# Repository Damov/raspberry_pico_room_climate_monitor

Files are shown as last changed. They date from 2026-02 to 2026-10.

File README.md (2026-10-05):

# Raspberry Pi Pico room climate monitor

A compact system based on the Raspberry Pi Pico designed for monitoring indoor climate conditions. The project integrates a <b>Raspberry Pi Pico 2 (RP2350)</b> microcontroller, a <b>Waveshare 2.7-inch E-Paper display module</b> (264 × 176 pixels), a <b>Waveshare BME280 environmental sensor</b>, and a <b>Hailege SCD41 CO₂ gas sensor</b>. Its purpose is to measure and display room temperature, humidity, atmospheric pressure, and CO₂ concentration. The software architecture is structured to support multiple screen layouts, which can be defined and switched via user input buttons.

# Screenshots

The following images illustrate the assembly of the system on a breadboard using jumper wires for all signal and power connections. The display is configured with a standard layout, presenting 15 minutes of historical data on the left side and three primary metrics on the right side: temperature, humidity, and CO₂ concentration. The four buttons select the home screen, previous layout, next layout, or a full refresh of the current view.

<p align="center">
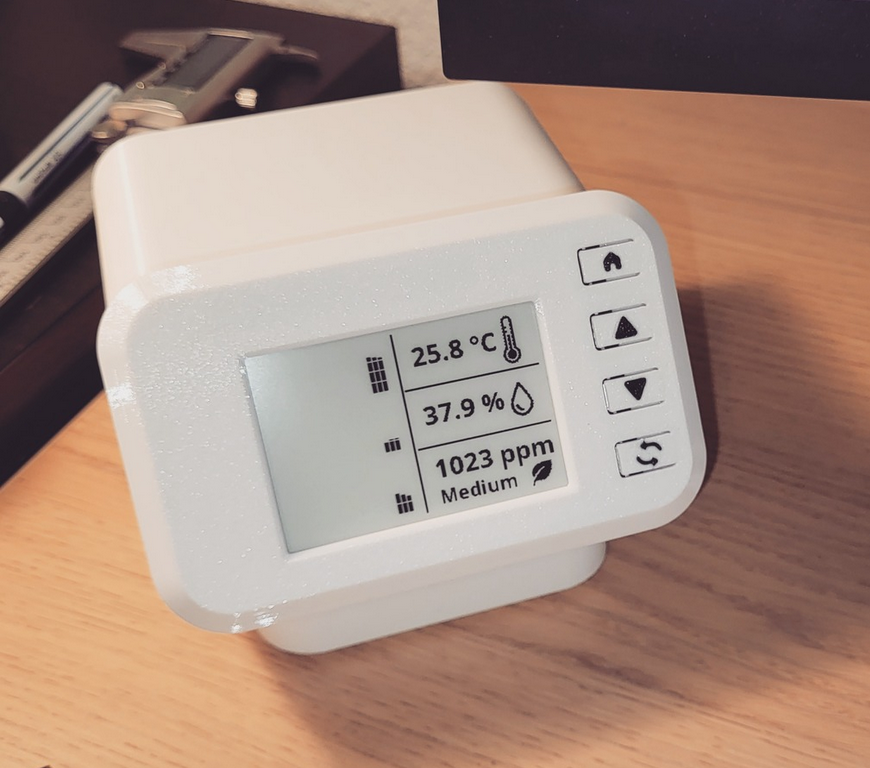
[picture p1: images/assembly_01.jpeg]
Assembly of the system, picture 1
  
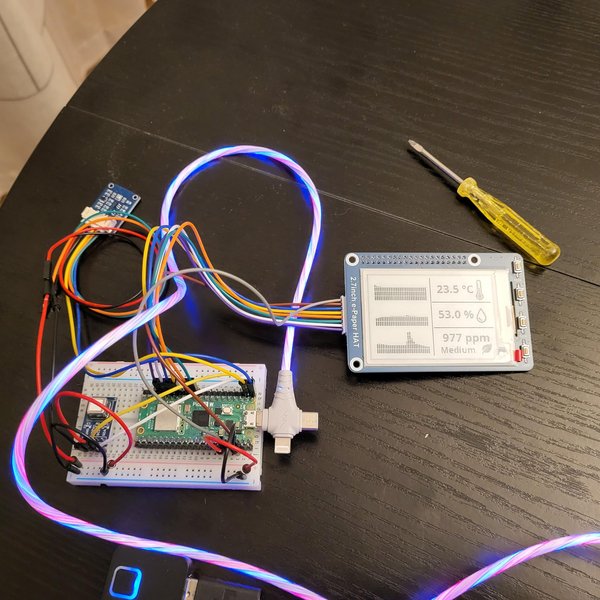
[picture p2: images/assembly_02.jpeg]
Assembly of the system, picture 2
  
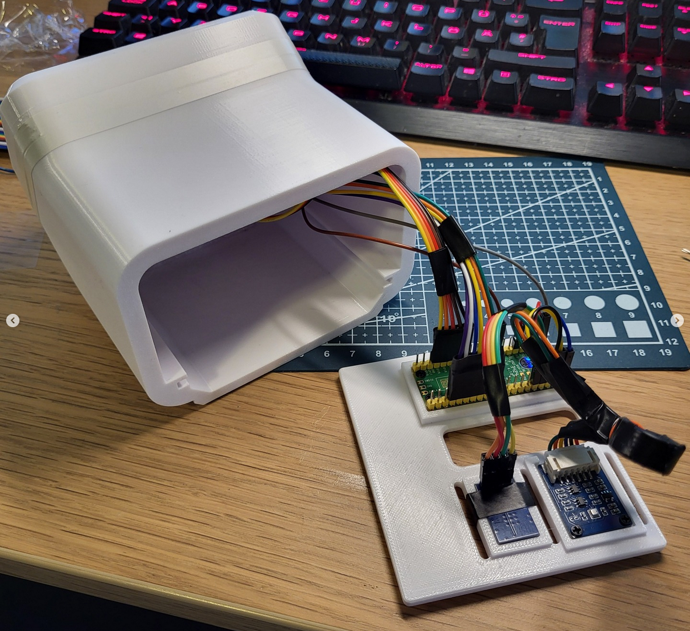
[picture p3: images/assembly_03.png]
Assembly of the system, picture 3
  
</p>

# New firmware design

The front page presents the current CO₂ concentration on the left, using a semicircular scale with Good / Medium / Bad / Very Bad in its centre and the value in ppm below. A short arrow indicates whether the concentration is rising or falling. Changes of 5% or less show no arrow. On the right, horizontal lines separate temperature, relative humidity, and sea-level pressure. The thermometer and water-drop symbols identify the first two readings, while Low / Normal / High indicates the pressure conditions. The following previews use illustrative readings.

<p align="center">
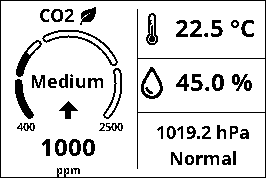
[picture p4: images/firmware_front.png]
New firmware front page with CO₂ scale, trend arrow, temperature, humidity, and sea-level pressure
  
</p>

The four 24-hour history pages display temperature, relative humidity, CO₂ concentration, and local atmospheric pressure. Each page presents a chart of 30-minute averages, followed by Current, Min, and Max in three aligned rows with their corresponding units. The time axis shows how many hours ago the measurements were recorded. The most recent values appear on the right. History is stored in RAM and starts again when the device is restarted.

<p align="center">
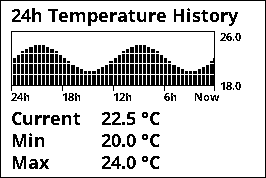
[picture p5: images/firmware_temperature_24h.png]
24-hour temperature history with Current, Min, and Max in degrees Celsius
  
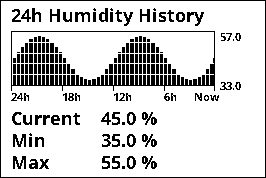
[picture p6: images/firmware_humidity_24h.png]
24-hour relative humidity history with Current, Min, and Max in per cent
  
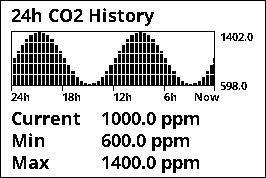
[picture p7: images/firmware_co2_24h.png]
24-hour CO₂ history with Current, Min, and Max in ppm
  
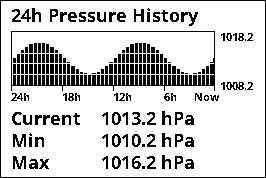
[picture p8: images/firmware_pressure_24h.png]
24-hour local pressure history with Current, Min, and Max in hPa
  
</p>

# Features
Shows current

* room temperaturen
* relative humidity
* CO2 concentration
* historic values

The firmware will be extended in future with further functionalities.

# Components
* <b>Raspberry Pi Pico 2 (RP2350) with presoldered pin header</b>
* <b>Waveshare 2.7-inch E-Paper display module</b> (264 × 176 pixels)
* <b>(Waveshare) BME280 environmental sensor</b>
* <b>(Hailege) SCD41 CO₂ gas sensor</b>

# Remarks

## Software architecture

The <a href="src/main.py"><b>main.py</b></a> file acts as the central module, handling sensor data acquisition and triggering screen updates. In contrast, the display layouts are defined in <a href="src/screen_manager.py"><b>screen_manager.py</b></a>, where you can configure and customize the screen layouts according to your requirements.

## No RTC clock required for this system

For development and testing, a Raspberry Pi Pico 2W is used, although this project does not rely on Wi‑Fi or Bluetooth connectivity. The logger.py module records measurement data relative to the datetime set at power-up. Because log data is stored in RAM, it is lost when the device is powered down, and the long-term logging buffer requires another 24 hours of operation to be refilled. Consequently, precise real-time clock accuracy is not critical for this application.

## Third-party libraries

This project uses Peter Hinch’s <a href="src/third_party_lib/write.py"><b>write.py</b></a> module from the <a href="https://github.com/peterhinch/micropython-font-to-py"><b>micropython-font-to-py</b></a> library. It is recommended not to modify this module within the project. Only update it as a whole file when necessary to incorporate a newer upstream version or bug fixes.

The <a href="src/drivers/screen_waveshare_2p7inch_module.py"><b>screen_waveshare_2p7inch_module.py</b></a> is the primary micropython driver for the 2.7-inch screen. It is also a third-party library which has been modified to allow to refresh the landscape frame buffer in partial and fast mode. The original file can be found <a href="https://github.com/waveshareteam/Pico_ePaper_Code/blob/main/python/Pico-ePaper-2.7_V2.py">here</a>.

# Getting started

This section describes assembling the hardware and installing the firmware for this system.

## Case geometry

The case geometry can be found in the <b>geometry</b> subfolder. This folder contains for the particular version the <b>STEP files</b> and the </b>3MF file</b>, which is suitable for 3D printing. The versioning of the case geometry does not necessarily correspond to the main firmware version number. Future versions of the case will be stored in this subfolder and labeled with their respective version numbers. The <b>3MF file</b> is typically optimized for the <b>Bambu Lab P1S</b> printer and may require adjustments for other printer models.

## Assembly

In this section, the assembly of the system is described. As mentioned in the introduction, the system integrates a <b>Raspberry Pi Pico microcontroller</b>, a <b>Waveshare 2.7‑inch E‑Paper display module</b> (264 × 176 pixels), a <b>Waveshare BME280</b> environmental sensor, and a <b>Hailege SCD41 CO₂</b> gas sensor.

The <b>BME280</b> sensor is connected to I2C bus 0, with the clock line (<b>SCL</b>) on <b>GP1</b> and the data line (<b>SDA</b>) on <b>GP0</b> of the Raspberry Pi Pico:

* SDA → GP0
* SCL → GP1

The <b>SCD51</b> sensor is connected to I2C bus 1, with the clock line (<b>SCL</b>) on <b>GP3</b> and the data line (<b>SDA</b>) on <b>GP2</b> of the Raspberry Pi Pico:

* SDA → GP2
* SCL → GP3

In this project, both sensors are using different I2C busses. However, both devices could also share the same I2C bus because they use different I2C addresses (BME280: <b>0x77</b>, SCD41: <b>0x62</b>). The sensors can be powered from either 3.3 V or 5 V, so they may be connected to <b>3V3(OUT)</b>, <b>VSYS</b>, or <b>VBUS</b> on the Pico depending on your power‑supply configuration. So, three different power pins can be used at the same time.

<p align="center">
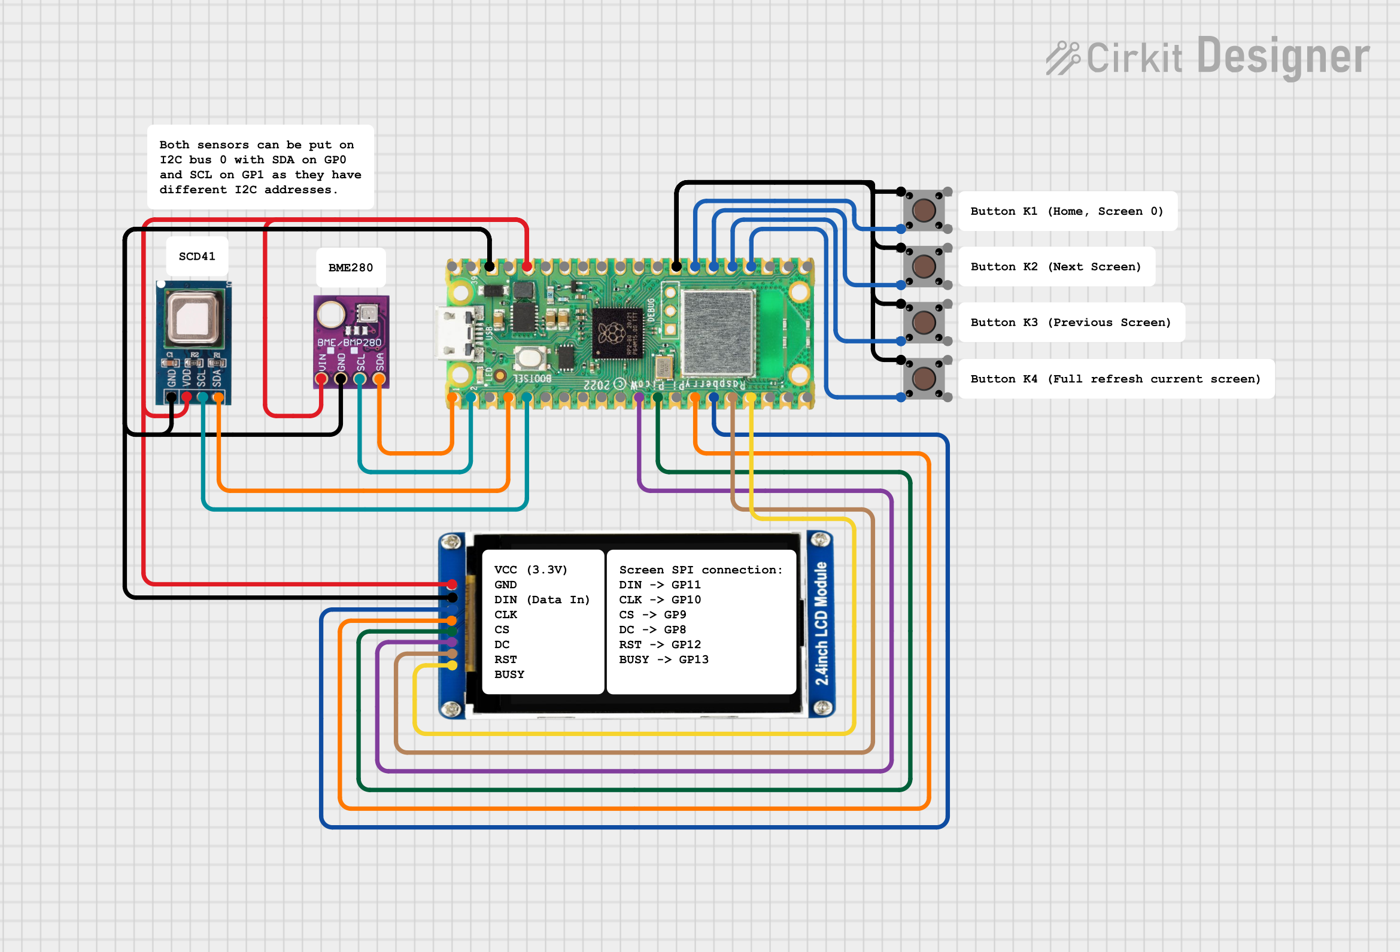
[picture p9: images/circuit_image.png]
Circuit layout
  
</p>

The display is wired using a JST‑to‑Dupont cable (<b>PH2.0, 20 cm, 8‑pin×1</b>), which is typically supplied with the module. The connections to the display are as follows:

* DIN → GP11
* CLK → GP10
* CS → GP9
* DC → GP8
* RST → GP12
* BUSY → GP13

To control the screen, four buttons (K1, K2, K3, K4) are used. Currently, five screen layouts are defined. The K4 button returns to screen 0 (the home screen), K3 (Up) switches to the previous screen layout, K2 (Down) advances to the next layout, and K1 refreshes the current view, as e‑Paper displays can sometimes show visual artifacts. The buttons share a common ground connection on the <b>Raspberry Pi Pico microcontroller</b>, with the <b>GP21</b> pin assigned to <b>K1</b>, <b>GP20</b> to <b>K2</b>, <b>GP19</b> to <b>K3</b>, and <b>GP18</b> to <b>K4</b> button:

* GND → K1 → GP21
* GND → K2 → GP20
* GND → K3 → GP19
* GND → K4 → GP18

Holding a button does nothing. Each completed press triggers one action only after the button is released. Both pressing and releasing must remain stable for 40 ms; very brief taps or glitches are ignored. Navigation wraps between layouts 0 and 4. Buttons held during startup must be released before they can trigger an action; that initial release does not trigger an action.

Buttons are sampled every 10 ms independently of sensor reads and e-paper refreshes. Completed clicks released while the display is busy are queued and applied in order once it is ready; the resulting layout is refreshed once per batch using the latest sensor data. Simultaneous releases are processed in K1, K2, K3, K4 order. The queue holds 32 presses; if it fills, additional presses are discarded and an overflow message is printed. Button actions do not trigger extra sensor reads or restart the 30-second measurement interval. Queued clicks take priority over a due measurement when cached readings are available; the measurement resumes once the pending clicks have been handled.

To reduce navigation delay, the driver uses 20 ms reset and post-busy settling waits, matching Waveshare's C driver, and sends landscape pixels in 22-byte SPI batches using a reusable row buffer. The driver still waits for BUSY to indicate readiness and retains full cleaning refreshes for navigation.

The start screen shows a monochrome CO2 gauge on the left, with Good / Medium / Bad / Very Bad in its centre and the current ppm value below. The eight-pixel-wide scale spans 400–2500 ppm and fills black from 400 ppm up to the current reading. The band and its fill have rounded ends. The remaining portion stays white with a two-pixel black outline; small gaps separate the four assessment sectors. At or below 400 ppm the scale is empty; at or above 2500 ppm it is full. Values outside that range keep their actual numeric reading. A leaf appears beside CO2; larger thermometer and water-drop icons sit before the temperature and humidity values on the right. The bottom row displays sea-level pressure in hPa and Low / Normal / High, without a pressure heading or icon. Pressure logs and the 24-hour pressure page retain local sensor readings.

A short, thick arrow below the CO2 assessment shows the change from the previous sensor reading (normally 30 seconds earlier). It points up or down only when the change exceeds `CO2_TREND_THRESHOLD_PERCENT = 5.0` in `src/main.py`, measured relative to the previous reading. Changes within the threshold, including exactly ±5%, show no arrow. Change this parameter to adjust sensitivity (for example, `2.0` hides changes of 2% or less); transfer the updated `main.py` and restart the Pico. The first reading and nonpositive readings show no arrow. Navigation and manual refreshes retain the cached trend without triggering extra measurements. Use `--trend up` or `--trend down` with the start-screen preview command to inspect the arrows.

Set `ALTITUDE_M = 50.0` near the top of `src/main.py` to the device height in metres above sea level. Transfer the updated file as `main.py` and restart the Pico after changing it. The start screen approximates sea-level pressure as `p_local / (1 - ALTITUDE_M / 44330.0) ** 5.255`. Low means below 1000 hPa, Normal means 1000 through 1020 hPa, and High means above 1020 hPa; these are broad orientation thresholds, not a weather forecast.

For a pixel-exact host preview using the bundled fonts, install Pillow and run `python3 tools/preview_start_screen.py --co2 2000 --output /tmp/climate-start-screen.png`. The preview does not access the device.

All four 24-hour history pages show Current, Min, and Max in three stacked rows. Labels are left-aligned in one column; each complete value-and-unit pair is left-aligned in the next column, with its unit directly after the number on the same line. Min and Max include the current reading; an empty history shows n/a. The chart redraws with each 30-second measurement using 30-minute bin averages, including the active bin. A nonempty active bin is visible immediately, even when its elapsed time is less than one pixel on the 24-hour scale. History is held in RAM and starts over after a device restart or firmware upload; it is not persisted.

To preview all history layouts with representative data, run `python3 tools/preview_history.py`; add `--empty` for empty history or `--output /tmp/history.png` to choose the output file. Pillow is required only for rendering previews, not for the unit tests.

Full page refreshes reinitialize the display controller, restore the complete RAM write window, and populate both image RAM planes. Partial updates use the reference driver's reset and border configuration and synchronize the reference image after completing the refresh. Normal updates follow the 30-second measurement cadence; after five soft updates, the next update performs a cleaning full refresh (approximately every three minutes). Only one refresh mode runs per cycle. Manual full refreshes restart the cleaning count and refresh timers. Automatic five-minute fast updates are removed; the fast-refresh API remains available and initializes its waveform before use. If drawing runs out of memory, the page is retried without refreshing an incomplete frame; three consecutive failures use the existing error handler.

**Firmware requirement:** MicroPython **1.27 or newer** for the Pico 2 (RP2 port), with hard interrupt timer support. Older firmware must be upgraded before running this version. Upload the new `button_controller.py` file together with `main.py` and the other files in `src/`.

## Firmware installation

### [1] Install MicroPython firmware on the Raspberry Pi Pico

When you have a completely new Raspberry Pi Pico 2, you will need to flash the MicroPython runtime onto the microcontroller. This is usually a very simple process. You can find an excellent tutorial at

<a href="https://www.raspberrypi.com/documentation/microcontrollers/micropython.html"><b>Flashing the Micropython runtime library on Raspberry Pi Pico</b></a>

The firmware for the Pico 2 version without a Wi‑Fi chip can be downloaded <a href="https://micropython.org/download/RPI_PICO2/RPI_PICO2-latest.uf2"><b>here</b></a>. Once the download is complete, press and hold the <b>BOOTSEL</b> button on the Pico while connecting it to your computer with a USB cable. After it is connected, release the <b>BOOTSEL</b> button - a new flash drive will appear in your computer’s file system. Drag and drop the downloaded firmware file onto this flash drive. When the copying is complete, the Pico will automatically unmount the drive. At this point, the MicroPython runtime has been successfully flashed onto your Raspberry Pi Pico board.

### [2] Installing Thonny editor and connect it with the Raspberry Pi Pico board

I usually use the <a href="https://thonny.org/"><b>Thonny editor</b></a> to transfer Python files onto the Raspberry Pi Pico board. I don’t use the editor for coding, but only to upload files to the board or make quick on‑the‑fly code adjustments.

This <a href="https://projects.raspberrypi.org/en/projects/getting-started-with-the-pico/0"><b>tutorial</b></a> explains the first steps with the Thonny editor and Raspberry Pi Pico very well. Alternatively, this <a href="https://www.youtube.com/watch?v=_ouzuI_ZPLs"><b>YouTube tutorial</b></a> also explains how to use the editor both for coding and for transferring files to the Pico board.

### [3] Downloading and installing the firmware on Raspberry Pi Pico 2

3.1. **Download the repository onto your local hard drive**:

```sh
   git clone git@github.com:Damov/raspberry_pi_room_climate_screen.git
```

3.2. **Transfer firmware on the Raspberry Pi Pico 2**:

Open the Thonny editor and select the Pico’s Python interpreter (it will appear in the list once the Pico is connected via a USB cable). In the editor's filesystem window, navigate to the folder on your computer where you cloned the repository. Once inside the repository, enter the subfolder <b>src/</b>. Now select all files from this subfolder, right‑click, and choose <b>Upload to /</b>. This will transfer everything from the <b>src/</b> subfolder to the Pico’s root directory. After the transfer is complete, you can disconnect the Pico from your computer and connect it to a power source using a USB cable. The system should now boot up and run the software.

<b>Note:</b> During boot, the MicroPython runtime on the board will look for the file <b>main.py</b> and execute it automatically. You can also run it manually from the Thonny editor. Simply double‑click <b>main.py</b> in the board’s file system. A new window will open showing the code with the title <b>[main.py]</b>. It’s important that the filename appears inside square brackets - this indicates that you’ve opened the file from the board’s storage, not from your computer. When you click the green <b>“Run”</b> button in Thonny, the code will execute directly on the board.

# Error indication and debugging

When an error occurs, the on-board LED of the Raspberry Pi Pico microcontroller will start blinking. Additionally, a file named <i>exception.log</i> will be created in the root directory of the Pico’s file system, containing the exception details and full traceback.

# Todo
* Add five small circles on the right side of the screen to indicate which screen layout is currently shown 
* ~~Display any unhandled exception directly on the screen, or alternatively, show a dedicated crash screen indicating that the system has failed.~~
* Define all configuration parameters in a config.ini file and load them at runtime.
* Add a barometer function and a simple weather forecast based on pressure trends over the last 3 hours.
* SCD41 module is actually connected on I2C bus 1 at scl_pin=GP3 and sda_pin=GP2, but is documented in the readme at I2C bus 0 (to be corrected).
* ~~Implement correct debouncing of the four physical pins~~
* ~~Design a 3D‑printable enclosure and publish the 3D model (e.g. as a download link).~~
* Write a practical tutorial and tips how to assemble the case. 
* Optional: Improve calibration of the sensor readings.
* Optional: Add a buzzer for acoustic alerts.

# Known issues
* Waveshare display class driver can cause out of memory exception
* Debouncing of four physical keys on the display does not work correctly with the current code in combination with interrupts

# Energy consumption

The average power consumption was measured using a USB power meter capable of tracking voltage and current, as shown in the image below:

<p align="center">
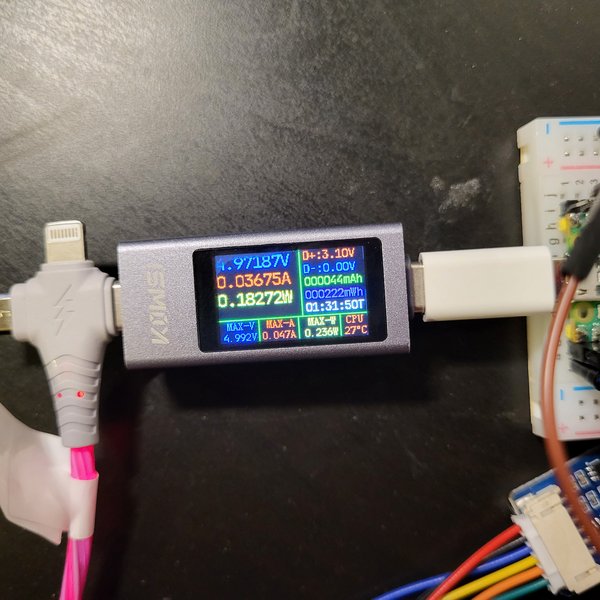
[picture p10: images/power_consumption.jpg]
  
</p>

Over a period of 1 hour and 32 minutes, the device consumed <b>222 mWh</b> of energy. This corresponds to an average power consumption of <b>144 mW</b> and an average current draw of <b>28.7 mA</b>. With an 1800 mAh LiPo battery, the device would operate for approximately 2 days and 12 hours. Therefore, for a stationary home installation, it is more practical to power the device directly via a USB wall adapter.

# Contributing

Contributions are welcome! Please feel free to submit a Pull Request.

# License
This project is licensed under the MIT License - see the LICENSE file for details.

# Acknowledgements
* <a href="https://github.com/peterhinch"><b>Peter Hinch</b></a>: For the writer class used for text rendering and font_to_py for fonts.
* <a href="https://github.com/waveshareteam/Pico_ePaper_Code"><b>Waveshare</b></a>: For the ePaper display and driver.
display 

## Button regression tests

Run the simulated button and main-loop tests on a computer from the repository root:

```sh
python3 -m unittest discover -s tests -v
```

On the Pico, verify K4 Home, K3 Up/Previous, K2 Down/Next, and K1 Refresh; hold each button to check that nothing happens until release, then confirm that it triggers once. Press Next twice during a full refresh and confirm that the resulting page advances twice. These hardware checks also verify timer operation with the installed firmware and the actual button contacts.

# Disclaimer
<b>This project and all associated files, documentation, and source code are provided “as is” without any express or implied warranties, including but not limited to the implied warranties of merchantability, fitness for a particular purpose, and non‑infringement. The author and contributors of this repository assume no responsibility or liability for any direct, indirect, incidental, or consequential damages that may occur through the use, modification, or distribution of the software and hardware designs contained herein. This includes, but is not limited to, hardware damage, data loss, malfunctioning devices, or personal injury that may arise from incorrect wiring, improper configuration, or misuse of the provided code and documentation. Users are encouraged to review, test, and verify all code before deploying it on any system. If you choose to use this project, you do so entirely at your own risk. By downloading, copying, modifying, or using any part of this project, you acknowledge that you have read, understood, and agree to this disclaimer.</b>

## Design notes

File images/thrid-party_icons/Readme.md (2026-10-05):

This sub-folder contains images as png format. Some of the symbols used in this project are third-party freeware icons obtained from various sources.

## [1] Symbols from Erik Flowers

The following symbols are used in this project:

    * wi--day-cloudy.png
    * wi--day-sunny.png
    * wi--rain.png
    * wi--raindrops.png
    * wi--thermometer.png

These symbols were created by <b>Erik Flowers</b> and are published under the <i>Open Font License</i> at the following link: https://icon-sets.iconify.design/wi/page-2.html?keyword=weather

The small start-screen icons in `images/thermometer.png`, `images/water-drop.png`, and `images/leaf.png` are cropped and scaled from the existing `images/static_screen1_background.png` artwork. Their one-byte-per-pixel device assets are stored in `src/img/` under the same names with a `.bin` extension. The leaf reuses the original background artwork; the thermometer and drop retain the existing icon attribution above.

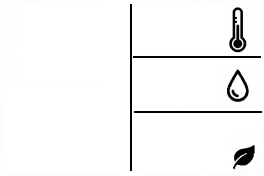
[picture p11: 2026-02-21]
images/static_screen1_background.png

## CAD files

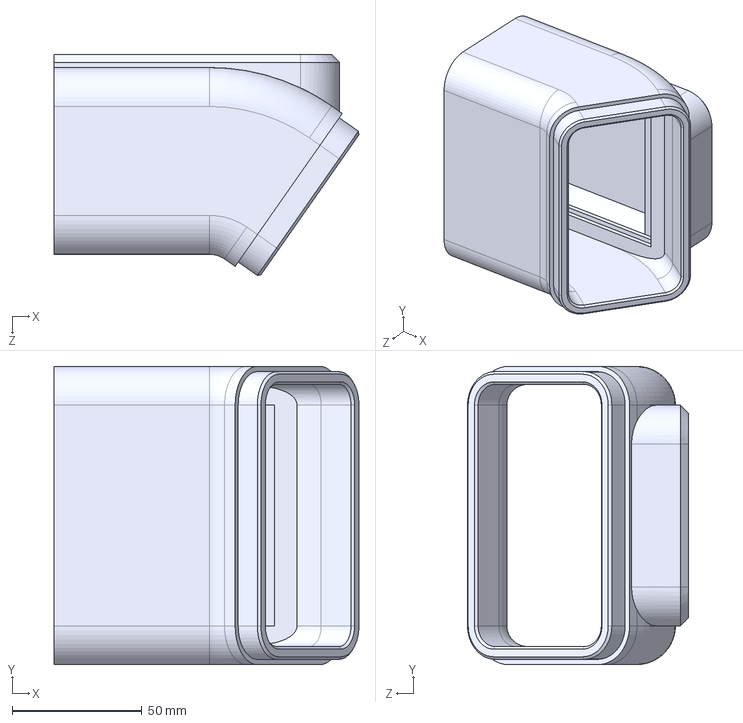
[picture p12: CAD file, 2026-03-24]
geometry/step - Version 0.1/main housing.STEP
117.6 x 115.0 x 85.2 mm

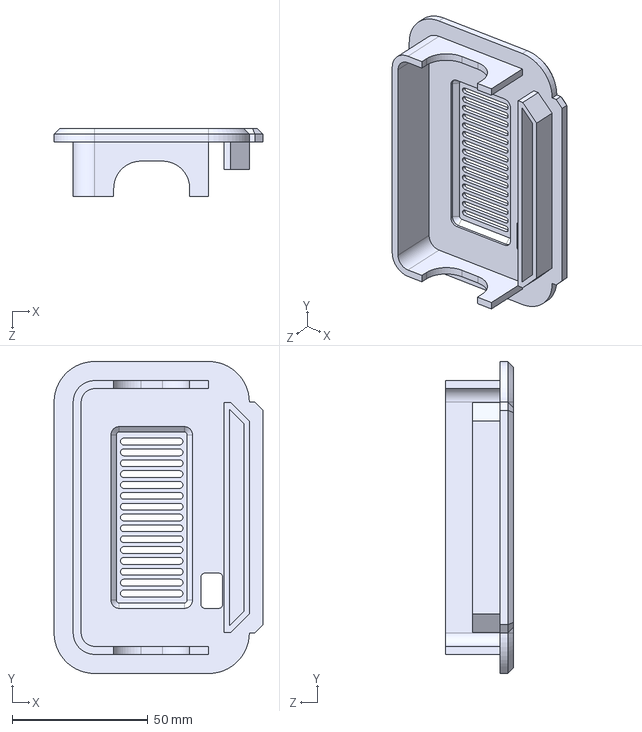
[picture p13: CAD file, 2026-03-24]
geometry/step - Version 0.1/back lid.STEP
77.0 x 115.0 x 25.0 mm

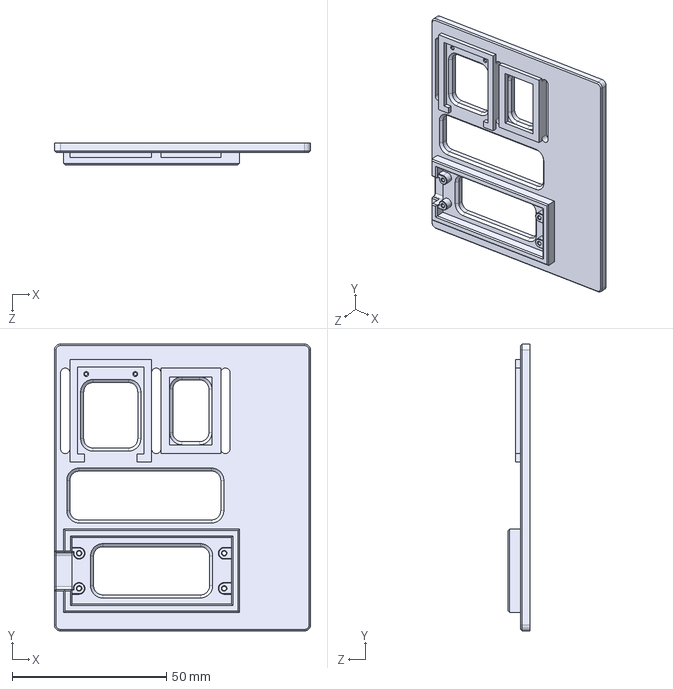
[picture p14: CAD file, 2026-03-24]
geometry/step - Version 0.1/board.STEP
83.0 x 93.0 x 7.00 mm

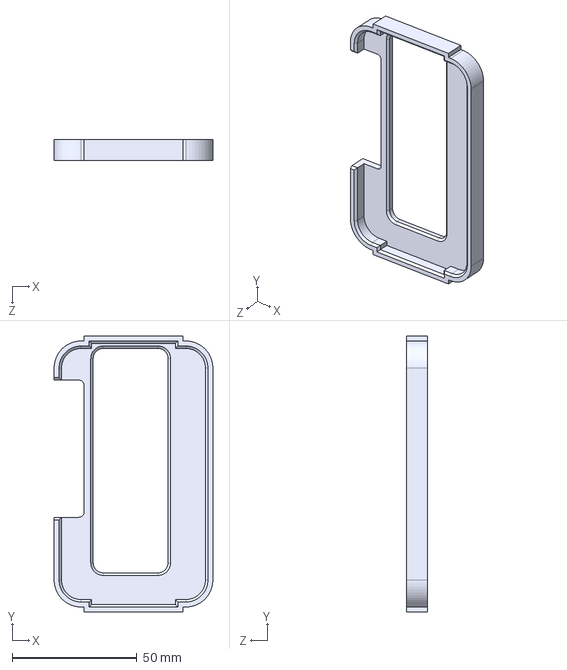
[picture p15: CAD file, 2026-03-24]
geometry/step - Version 0.1/display frame.STEP
63.7 x 110.7 x 8.40 mm

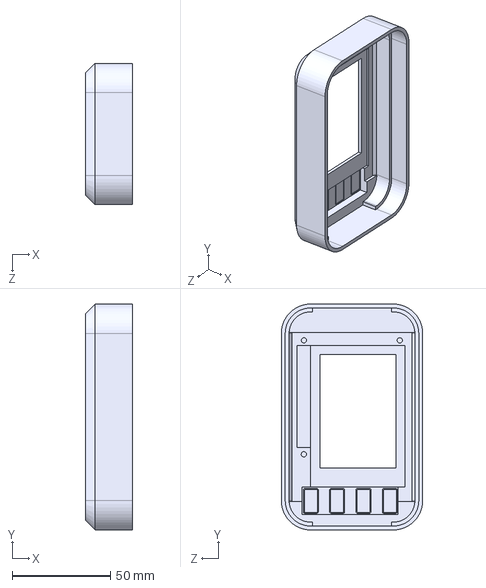
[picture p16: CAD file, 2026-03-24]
geometry/step - Version 0.1/front Lid.STEP
24.0 x 115.0 x 72.0 mm

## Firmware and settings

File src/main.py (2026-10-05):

"""
=============================================================================
main.py

Main script for the Raspberry Pico Room Climate Monitor. It initializes sensors,
logger, and screen, and continuously reads sensor data, logs it, and updates
the screen.

Part of the Open source project: Raspberry Pico Room Climate Monitor
See: https://github.com/Damov/raspberry_pico_room_climate_monitor
=============================================================================
"""

import machine
from utime import sleep, sleep_ms, ticks_ms, ticks_diff
import gc

from drivers.screen_waveshare_2p7inch_module import EPD_2in7_V2
from screen_manager import ScreenManager
from screen_writer import ScreenWriter
from logger import Logger
from button_controller import ButtonController, apply_button

from drivers.SCD41_driver import SCD41
from drivers.BME280_driver import BME280

from fonts import OpenSansBold_28, OpenSansBold_20

from error_handling import show_exception_on_screen, write_exception_to_file

#-- Site configuration ------------------------------------------------
ALTITUDE_M = 50.0 #........................................ Device height above sea level in metres; used by the start-screen pressure display

CO2_TREND_THRESHOLD_PERCENT = 5.0 #........................ Minimum relative change for an arrow; changes within this percentage are stable


def print_mem(label=""):
    """
        Print the current memory usage (free and allocated) 
        with an optional label for context.

        This function is useful for debugging memory usage at
        different points in the code.
    """
    #import gc #........................................................ Import garbage collector module to check memory usage
    #gc.collect() #..................................................... Run garbage collection to free up memory before checking usage
    print(
        label,
        f"alloc: {gc.mem_alloc()}, "
        f"free: {gc.mem_free()} ({100*gc.mem_free()/(gc.mem_free() + gc.mem_alloc()):.2f}) %"
    ) #................................................................. Print the label along with free and allocated memory in bytes for debugging purposes


def refresh_screen(screen_writer, refresh_state, force_full=False, measurement_due=False):
    """
        Select one refresh and update scheduling state only after success.

        Full refreshes clean ghosting after five soft updates or 15 minutes.
        Normal partial updates follow the 30-second measurement cadence.
        Manual full refreshes restart both timers and the soft-update count.
    """
    now = ticks_ms()
    if (force_full or refresh_state["soft_updates"] >= 5 or
            ticks_diff(now, refresh_state["last_full"]) >= 15 * 60 * 1000):
        screen_writer.show()
        completed = ticks_ms()
        refresh_state["last_full"] = completed
        refresh_state["last_partial"] = completed
        refresh_state["soft_updates"] = 0
        print("Screen refresh: full; soft-update count reset")
        return "full"
    elif measurement_due: #.............................. Refresh each newly measured frame without adding a second interval
        screen_writer.show_partial()
        refresh_state["last_partial"] = ticks_ms()
        refresh_state["soft_updates"] += 1
        print(f"Screen refresh: partial {refresh_state['soft_updates']}/5")
        return "partial"
    return None #.......................................... No refresh is due yet


def co2_trend(current, previous, threshold_percent):
    """Compare consecutive readings, returning up (1), down (-1), or stable (0)."""
    if threshold_percent < 0:
        raise ValueError("CO2 trend threshold must be nonnegative")
    if (previous is None or current is None or
            not previous > 0 or not current > 0):
        return 0
    change = current - previous
    threshold = previous * threshold_percent / 100
    if abs(change) <= threshold:
        return 0
    return 1 if change > 0 else -1


def main():
    """Initialize button sampling and always stop it when the application exits."""
#-- Define active-low K1, K2, K3, K4 inputs ----------------------------
    pins = tuple(
        machine.Pin(number, machine.Pin.IN, machine.Pin.PULL_UP)
        for number in (21, 20, 19, 18)
    ) #............................................................... GP21 Refresh, GP20 Next, GP19 Previous, GP18 Home
    buttons = ButtonController(pins)
    try:
        _run_monitor(buttons)
    finally:
        buttons.close() #............................................. Stop the timer on errors and KeyboardInterrupt


def _run_monitor(buttons):
    """
        Initialize sensors, logger, and screen, then process button events
        independently of the periodic sensor measurements.
    """
#-- Variables required to control the device with buttons -------------
    SCR_LAYOUT_NUMBER     = 0 #....................................... Current screen layout (0-4)
    SCR_MAX_LAYOUT_NUMBER = 4 #....................................... Five available screen layouts
    SCR_FULL_REFRESH      = False #................................... Full refresh requested by a button event
    WAIT_INTERVAL_MS      = 30 * 1000 #............................... Sensor sampling interval in milliseconds
    draw_failures         = 0 #....................................... Consecutive failures while drawing the selected page
    last_measurement      = None #................................... Read sensors before drawing the first page
    previous_co2          = None #................................... No trend until two sensor readings exist
    co2_direction         = 0 #...................................... Cache the trend between measurements and page changes

#-- Set time refresh intervals to current time ------------------------
    refresh_state = {
        "last_full": ticks_ms(),
        "last_partial": ticks_ms(),
        "soft_updates": 0
    }
    first_refresh = True

#-- Initialize the short-term Logger ----------------------------------
    MAX_BIN_HISTORY = 0.25 * 3600 #............... Keep 15 minutes of history in seconds
    BIN_TIMESPAN    = 0.5 * 60 #.................. Bin width of 30 seconds for output in seconds

    logger_pressure_shortterm = Logger(
            max_bin_history = MAX_BIN_HISTORY, #.. Keep 15 minutes of history
            bin_timespan = BIN_TIMESPAN #......... Bin width of 30 seconds for output
        )

    logger_temperature_shortterm = Logger(
            max_bin_history = MAX_BIN_HISTORY, #.. Keep 15 minutes of history
            bin_timespan = BIN_TIMESPAN #......... Bin width of 30 seconds for output
        )

    logger_humidity_shortterm = Logger(
            max_bin_history = MAX_BIN_HISTORY, #.. Keep 15 minutes of history
            bin_timespan = BIN_TIMESPAN #......... Bin width of 30 seconds for output
        )

    logger_co2_shortterm = Logger(
            max_bin_history = MAX_BIN_HISTORY, #.. Keep 15 minutes of history
            bin_timespan = BIN_TIMESPAN #......... Bin width of 30 seconds for output
        )

#-- Initialize the 24h-term Logger ----------------------------------
    MAX_BIN_HISTORY = 24 * 3600 #................. Keep 24 hours of history in seconds
    BIN_TIMESPAN    = 30 * 60 #................... Bin width of 30 minutes for output in seconds

    logger_pressure_24h = Logger(
            max_bin_history = MAX_BIN_HISTORY, #.. Keep 24 hours of history
            bin_timespan = BIN_TIMESPAN #......... Bin width of 30 minutes for output
        )

    logger_temperature_24h = Logger(
            max_bin_history = MAX_BIN_HISTORY, #.. Keep 24 hours of history
            bin_timespan = BIN_TIMESPAN #......... Bin width of 30 minutes for output
        )

    logger_humidity_24h = Logger(
            max_bin_history = MAX_BIN_HISTORY, #.. Keep 24 hours of history
            bin_timespan = BIN_TIMESPAN #......... Bin width of 30 minutes for output
        )

    logger_co2_24h = Logger(
            max_bin_history = MAX_BIN_HISTORY, #.. Keep 24 hours of history
            bin_timespan = BIN_TIMESPAN #......... Bin width of 30 minutes for output
        )

#-- Initialize the screen ---------------------------------------------
    epd = EPD_2in7_V2()

#-- Create a ScreenWriter instance ------------------------------------
    screen_writer = ScreenWriter(
            screen_driver = epd,
            font = OpenSansBold_28,
            verbose = True
        )
    
#-- Refresh screen --------------------------------------------------------
    screen_writer.show() #......................... First full refresh

#-- Show splash screen ------------------------------------------------
    fname = "img/splash_screen.bin"
    img_width  = 264
    img_height = 176

    screen_writer.add_image(
        fname,
        img_width,
        img_height,
        x=0,
        y=0,
        do_gc = True,
        show_after = False
    ) #............................. Add splash screen image to the screen

    screen_writer.change_font(OpenSansBold_20)
    screen_writer.add_text(
            "Loading...",
            85,
            155,
            invert=False
        ) #......................... Add "Loading..." text to the screen
    screen_writer.change_font(OpenSansBold_28)
    screen_writer.show() #.......... Show the splash screen with the loading message

#-- Create a ScreenManager instance -----------------------------------
    screen_manager = ScreenManager(screen_writer, altitude_m=ALTITUDE_M)

#-- Init sensors ------------------------------------------------------
    sensor_bme280 = BME280(
            i2c_bus_id = 0,
            scl_pin = 1,
            sda_pin = 0,
            bme_addr = 0x77,
            freq=100000
        ) #............................................. Initialize BME280 sensor

    sensor_scd41 = SCD41(
            i2c_bus_id=1,
            scl_pin=3,
            sda_pin=2,
            address=0x62,
            freq=100000
        ) #............................................. Initialize SCD41 sensor
    
    while True:
    #-- Check if a new sensor measurement is due --------------------------
        now = ticks_ms()
        measurement_due = (
            last_measurement is None or
            (ticks_diff(now, last_measurement) >= WAIT_INTERVAL_MS and
             buttons.pending() == 0)
        ) #............................................... Serve queued clicks from cached data before taking a due measurement
        if measurement_due:
        #-- Read and log the latest sensor measurements -----------------------
            gc.collect() #................................ Free memory before reading the sensors
            print_mem("before loop step")

            new_co2, _, _ = sensor_scd41.read_measurement()
            temp, pressure, hum = sensor_bme280.read_compensated()
            co2_direction = co2_trend(new_co2, previous_co2, CO2_TREND_THRESHOLD_PERCENT)
            CO2 = new_co2
            previous_co2 = new_co2 #...................... Advance the reference only after successful sensor reads

            print_mem("after sensors")

        #-- Add new samples to the loggers ------------------------------------
            now_timestamp = ticks_ms() #............................. Current time in ms

            logger_pressure_shortterm.add(now_timestamp, pressure) #. Add new pressure sample to the short-term logger
            logger_temperature_shortterm.add(now_timestamp, temp) #.. Add new temperature sample to the short-term logger
            logger_humidity_shortterm.add(now_timestamp, hum) #...... Add new humidity sample to the short-term logger
            logger_co2_shortterm.add(now_timestamp, CO2) #........... Add new CO2 sample to the short-term logger

            logger_pressure_24h.add(now_timestamp, pressure) #....... Add new pressure sample to the short-term logger
            logger_temperature_24h.add(now_timestamp, temp) #........ Add new temperature sample to the 24h logger
            logger_humidity_24h.add(now_timestamp, hum) #............ Add new humidity sample to the 24h logger
            logger_co2_24h.add(now_timestamp, CO2) #................. Add new CO2 sample to the 24h logger

            print_mem("after logger")

            last_measurement = ticks_ms() #................ Start the next interval after reading and logging

    #-- Apply one bounded batch of presses captured during any work -------
        for _ in range(buttons.pending()):
            button = buttons.pop()
            SCR_LAYOUT_NUMBER = apply_button(
                SCR_LAYOUT_NUMBER, button, SCR_MAX_LAYOUT_NUMBER + 1
            )
            SCR_FULL_REFRESH = True #...................... K1 also refreshes when the layout stays the same
            print(f"K{button} button released: screen layout {SCR_LAYOUT_NUMBER}")

        if buttons.take_overflow():
            print("Button queue full: new presses were discarded.")

    #-- Wait briefly when neither measurements nor buttons need drawing ---
        if not measurement_due and not SCR_FULL_REFRESH:
            sleep_ms(10) #................................ Avoid busy polling while the timer samples inputs
            continue

    #-- Draw the selected layout with the latest sensor data --------------
        gc.collect() #..................................................... Run garbage collection to free up memory before the next loop iteration
        try:
            print(f"Drawing screen layout {SCR_LAYOUT_NUMBER} ...")
            if SCR_LAYOUT_NUMBER == 0:
                screen_manager.screen1(
                            temp,
                            hum,
                            pressure,
                            CO2,
                            logger_temperature_shortterm,
                            logger_humidity_shortterm,
                            logger_co2_shortterm,
                            co2_trend_direction=co2_direction
                    ) #.............................................. Draw the first screen layout with the latest sensor readings and loggers for short-term history
            elif SCR_LAYOUT_NUMBER == 1:
                screen_manager.screen2_24h_temperature_history(
                                temp,
                                logger_temperature_24h
                            )
            elif SCR_LAYOUT_NUMBER == 2:
                screen_manager.screen3_24h_humidity_history(
                                    hum,
                                    logger_humidity_24h
                            )
            elif SCR_LAYOUT_NUMBER == 3:
                screen_manager.screen4_24h_co2_history(
                                    CO2,
                                    logger_co2_24h
                            )
            elif SCR_LAYOUT_NUMBER == 4:
                screen_manager.screen5_24h_pressure_history(
                                    pressure,
                                    logger_pressure_24h
                            )
            else:
                raise ValueError(f"Invalid screen mode: {SCR_LAYOUT_NUMBER}") #........ Reject an invalid screen layout
        except MemoryError as e:
            draw_failures += 1
            print(f"MemoryError drawing layout {SCR_LAYOUT_NUMBER}: {e}")
            if draw_failures >= 3:
                raise #................................... Report persistent failures through the existing error handler
            SCR_FULL_REFRESH = True #...................... Retry the selected page without another button press
            gc.collect()
            sleep_ms(50)
            continue #.................................... Never refresh an incomplete frame after drawing fails
        draw_failures = 0

    #-- Select one refresh and commit its state only after success --------
        refresh_screen(
            screen_writer, refresh_state,
            force_full=first_refresh or SCR_FULL_REFRESH,
            measurement_due=measurement_due
        )
        first_refresh = False
        SCR_FULL_REFRESH = False

        print_mem("after screen")


if __name__ == "__main__":
#-- Define on-board LED pin -----------------------------------------------
    error_led = machine.Pin("LED", machine.Pin.OUT) #................. On‑board LED (Pico default)

#-- Start execution of the main function and handle exceptions ------------
    try:
        error_led.value(1) #.......................................... Turn on the error LED
        main() #...................................................... Start the main function
    except Exception as e:
    #-- Write Exception to file -------------------------------------------
        write_exception_to_file(e, file_path="exception.log") #....... Write the exception traceback to a log file for later analysis
        show_exception_on_screen(e, show_traceback=False) #........... Display the exception on the e‑paper screen

    #-- Blink the LED to indicate an error --------------------------------
        while True:
            dT_interval = 0.5 # seconds
            error_led.value(1)
            sleep(dT_interval)
            error_led.value(0)
            sleep(dT_interval)

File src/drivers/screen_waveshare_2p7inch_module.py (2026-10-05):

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

# =============================================================================
#  MODIFICATION HISTORY WITHIN THIS PROJECT
# -----------------------------------------------------------------------------
# 2026-02-22 : added method display_Landscape_Fast()
# 2026-02-22 : added method display_Landscape_Partial()
# 2026-10-05 : restore controller state and RAM addresses for page updates
# 2026-10-05 : maintain both image RAM planes across full and soft updates
# 2026-10-05 : shorten controller waits and batch landscape SPI transfers
# =============================================================================

from machine import Pin, SPI
import framebuf
import utime

# Display resolution
EPD_WIDTH       = 176
EPD_HEIGHT      = 264

RST_PIN         = 12
DC_PIN          = 8
CS_PIN          = 9
BUSY_PIN        = 13

LUT_DATA_4Gray = [
        0x40,0x48,0x80,0x0,0x0,0x0,0x0,0x0,0x0,0x0,0x0,0x0,
        0x8,0x48,0x10,0x0,0x0,0x0,0x0,0x0,0x0,0x0,0x0,0x0,
        0x2,0x48,0x4,0x0,0x0,0x0,0x0,0x0,0x0,0x0,0x0,0x0,
        0x20,0x48,0x1,0x0,0x0,0x0,0x0,0x0,0x0,0x0,0x0,0x0,
        0x0,0x0,0x0,0x0,0x0,0x0,0x0,0x0,0x0,0x0,0x0,0x0,
        0xA,0x19,0x0,0x3,0x8,0x0,0x0,                    
        0x14,0x1,0x0,0x14,0x1,0x0,0x3,                    
        0xA,0x3,0x0,0x8,0x19,0x0,0x0,                    
        0x1,0x0,0x0,0x0,0x0,0x0,0x1,                    
        0x0,0x0,0x0,0x0,0x0,0x0,0x0,                    
        0x0,0x0,0x0,0x0,0x0,0x0,0x0,                    
        0x0,0x0,0x0,0x0,0x0,0x0,0x0,                    
        0x0,0x0,0x0,0x0,0x0,0x0,0x0,                    
        0x0,0x0,0x0,0x0,0x0,0x0,0x0,                    
        0x0,0x0,0x0,0x0,0x0,0x0,0x0,                    
        0x0,0x0,0x0,0x0,0x0,0x0,0x0,                    
        0x0,0x0,0x0,0x0,0x0,0x0,0x0,                    
        0x22,0x22,0x22,0x22,0x22,0x22,0x0,0x0,0x0,            
        0x22,0x17,0x41,0x0,0x32,0x1C,
        ]


class EPD_2in7_V2:
    def __init__(self):
        self.reset_pin = Pin(RST_PIN, Pin.OUT)
        
        self.busy_pin = Pin(BUSY_PIN, Pin.IN, Pin.PULL_UP)
        self.cs_pin = Pin(CS_PIN, Pin.OUT)
        self.width = EPD_WIDTH
        self.height = EPD_HEIGHT
        
        self.black = 0x00
        self.white = 0xff
        self.darkgray = 0xaa
        self.grayish = 0x55
        
        self.LUT_DATA_4Gray = LUT_DATA_4Gray
        
        self.spi = SPI(1)
        self.spi.init(baudrate=4000_000)
        self.dc_pin = Pin(DC_PIN, Pin.OUT)
        
        self.buffer_1Gray_Landscape = bytearray(self.height * self.width // 8)
        self.buffer_1Gray_Portrait = bytearray(self.height * self.width // 8)
        self.buffer_4Gray = bytearray(self.height * self.width // 4)
        self._landscape_row = bytearray((self.width + 7) // 8) #.... Reuse one row for batched SPI transfers
        
        self.image1Gray_Landscape = framebuf.FrameBuffer(self.buffer_1Gray_Landscape, self.height, self.width, framebuf.MONO_VLSB)
        self.image1Gray_Portrait = framebuf.FrameBuffer(self.buffer_1Gray_Portrait, self.width, self.height, framebuf.MONO_HLSB)
        self.image4Gray = framebuf.FrameBuffer(self.buffer_4Gray, self.width, self.height, framebuf.GS2_HMSB)
        
        self.init()
        self.clear()
        utime.sleep_ms(500)

    def digital_write(self, pin, value):
        pin.value(value)

    def digital_read(self, pin):
        return pin.value()

    def delay_ms(self, delaytime):
        utime.sleep(delaytime / 1000.0)

    def spi_writebyte(self, data):
        self.spi.write(bytearray(data))

    def module_exit(self):
        self.digital_write(self.reset_pin, 0)

    # Hardware reset
    def reset(self):
        self.digital_write(self.reset_pin, 1)
        self.delay_ms(20)
        self.digital_write(self.reset_pin, 0)
        self.delay_ms(2)
        self.digital_write(self.reset_pin, 1)
        self.delay_ms(20)

    def send_command(self, command):
        self.digital_write(self.dc_pin, 0)
        self.digital_write(self.cs_pin, 0)
        self.spi_writebyte([command])
        self.digital_write(self.cs_pin, 1)

    def send_data(self, data):
        self.digital_write(self.dc_pin, 1)
        self.digital_write(self.cs_pin, 0)
        self.spi_writebyte([data])
        self.digital_write(self.cs_pin, 1)
        
    def send_data1(self, buf):
        self.digital_write(self.dc_pin, 1)
        self.digital_write(self.cs_pin, 0)
        self.spi.write(bytearray(buf))
        self.digital_write(self.cs_pin, 1)
        
    def ReadBusy(self):
        print("e-Paper busy")
        while(self.digital_read(self.busy_pin) == 1):      #  1: busy, 0: ready
            self.delay_ms(2)
        self.delay_ms(20)
        print("e-Paper busy release")
        
    def TurnOnDisplay(self):
        self.send_command(0x22) #Display Update Control
        self.send_data(0xF7)
        self.send_command(0x20) #Activate Display Update Sequence
        self.ReadBusy()
        
    def TurnOnDisplay_Fast(self):
        self.send_command(0x22) #Display Update Control
        self.send_data(0xC7)
        self.send_command(0x20) #Activate Display Update Sequence
        self.ReadBusy()
        
    def TurnOnDisplay_Partial(self):
        self.send_command(0x22) #Display Update Control
        self.send_data(0xFF)
        self.send_command(0x20) #Activate Display Update Sequence
        self.ReadBusy()
        
    def TurnOnDisplay_4GRAY(self):
        self.send_command(0x22) #Display Update Control
        self.send_data(0xC7)
        self.send_command(0x20) #Activate Display Update Sequence
        self.ReadBusy()
            
        
    def Lut(self):
        self.send_command(0x32)
        for i in range(159):
            self.send_data(self.LUT_DATA_4Gray[i])
            
    def init(self):
            
        # EPD hardware init start
        self.reset()
        self.ReadBusy()

        self.send_command(0x12) #SWRESET
        self.ReadBusy()

        self.send_command(0x45) #set Ram-Y address start/end position          
        self.send_data(0x00)
        self.send_data(0x00)
        self.send_data(0x07) #0x0107-->(263+1)=264
        self.send_data(0x01)

        self.send_command(0x4F)   # set RAM y address count to 0;    
        self.send_data(0x00)
        self.send_data(0x00)

        self.send_command(0x11)  # data entry mode
        self.send_data(0x03)
        return 0
        
    def init_Fast(self):
            
        # EPD hardware init start
        self.reset()
        self.ReadBusy()

        self.send_command(0x12) #SWRESET
        self.ReadBusy()

        self.send_command(0x12) #SWRESET
        self.ReadBusy()

        self.send_command(0x18) #Read built-in temperature sensor
        self.send_data(0x80)    

        self.send_command(0x22) # Load temperature value
        self.send_data(0xB1)    
        self.send_command(0x20)    
        self.ReadBusy()
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

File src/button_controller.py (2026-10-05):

"""
=============================================================================
button_controller.py

Debounced button input for the Raspberry Pico Room Climate Monitor. A hard
interrupt timer captures presses while sensors and the display are busy.

Part of the Open source project: Raspberry Pico Room Climate Monitor
See: https://github.com/Damov/raspberry_pico_room_climate_monitor
=============================================================================
"""

import machine
import micropython
from utime import ticks_ms, ticks_diff


class ButtonController:
    """
        Sample active-low buttons and queue one event per completed press and release.

        Arguments:
        ----------
            pins: tuple
                K1, K2, K3, K4 input pins, in that order.

        Notes:
        ------
            Requires MicroPython 1.27 or newer on RP2. Press and release must
            remain stable for 40 ms. Holding a button does nothing; the action
            triggers on release. Buttons held at startup are ignored until
            released, without triggering an action on that initial release. The main
            loop handles navigation and display updates.
    """
    SAMPLE_INTERVAL_MS = 10
    DEBOUNCE_MS = 40
    QUEUE_SIZE = 32

    def __init__(self, pins):
    #-- Allocate all state before starting the interrupt timer ------------
        self._pins = pins
        self._raw = bytearray(pin.value() for pin in pins)
        self._stable = bytearray(self._raw)
        self._armed = bytearray(len(pins)) #............... Require a stable release before the first press
        self._pressed = bytearray(len(pins)) #............. Remember valid presses until their stable release
        self._changed_at = [ticks_ms()] * len(pins)
        self._queue = bytearray(self.QUEUE_SIZE)
        self._head = 0
        self._tail = 0
        self._count = 0
        self._overflow = False
        self._timer = machine.Timer(-1)
        micropython.alloc_emergency_exception_buf(100) #... Allow interrupt errors to include a traceback

    #-- Start sampling independently of the main loop ---------------------
        try:
            self._timer.init(
                period=self.SAMPLE_INTERVAL_MS,
                mode=machine.Timer.PERIODIC,
                callback=self._sample,
                hard=True
            )
        except BaseException:
            self._timer.deinit()
            raise

    def _sample(self, timer):
        """
            Debounce input and enqueue completed clicks in K1-K4 release order.

            This runs in hard interrupt context: do not allocate memory, print,
            sleep, access sensors, or update the display here. Queue indices and
            counters stay bounded so their arithmetic uses small integers.
        """
        now = ticks_ms()
        index = 0
        while index < len(self._pins):
            value = self._pins[index].value()
            if value != self._raw[index]:
                self._raw[index] = value
                self._changed_at[index] = now
            elif ticks_diff(now, self._changed_at[index]) >= self.DEBOUNCE_MS:
                if value == 1:
                    self._stable[index] = 1
                    if self._pressed[index]:
                        self._pressed[index] = 0 #........ Consume the click exactly once after stable release
                        if self._count < self.QUEUE_SIZE:
                            self._queue[self._tail] = index + 1
                            self._tail = (self._tail + 1) % self.QUEUE_SIZE
                            self._count += 1
                        else:
                            self._overflow = True #....... Keep older events and discard this completed click
                    self._armed[index] = 1 #............... Allow a new press after the stable release
                elif self._stable[index] != 0:
                    self._stable[index] = 0
                    if self._armed[index]:
                        self._armed[index] = 0
                        self._pressed[index] = 1 #........ Remember the press; holding never queues an action
            index += 1

    def pending(self):
        """Return the current number of queued clicks for one bounded batch."""
        return self._count

    def pop(self):
        """Return the oldest completed click as a button number (1-4), or zero if the queue is empty."""
    #-- Protect shared queue state from the sampling interrupt ------------
        irq_state = machine.disable_irq()
        try:
            if not self._count:
                return 0
            button = self._queue[self._head]
            self._head = (self._head + 1) % self.QUEUE_SIZE
            self._count -= 1
            return button
        finally:
            machine.enable_irq(irq_state)

    def take_overflow(self):
        """Read and clear the overflow flag; report it only from the main loop."""
        irq_state = machine.disable_irq()
        try:
            overflow = self._overflow
            self._overflow = False
            return overflow
        finally:
            machine.enable_irq(irq_state)

    def close(self):
        """Stop sampling before returning to the REPL or handling an error."""
        self._timer.deinit()


def apply_button(layout, button, layout_count=5):
    """Return the selected layout using K1 Refresh, K2 Next, K3 Previous, K4 Home."""
    if button == 4:
        return 0
    if button == 3:
        return (layout - 1) % layout_count
    if button == 2:
        return (layout + 1) % layout_count
    return layout #........................................ K1 requests a refresh without changing the page

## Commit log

2026-02-20 Add image for documenting the wiring of the entire system.
2026-02-20 add BME280 driver
2026-02-20 add SCD41 driver
2026-02-20 add waveshare 2.7inch ePaper screen driver
2026-02-22 utilising the logger for short term measurement in the code
    [main.py]
2026-02-22 add remarks what has been modified in the e-paper screen driver
2026-02-26 handle exception, log them and let LED blink
2026-02-28 Redesign the logger class to be memory friendly
    [logger.py, main.py, screen_manager.py]
2026-02-28 Updated information of power consumption
2026-03-01 Turn on on-board LED permamently during the operation
2026-03-01 Define short-term and long-term logger
    [main.py]
2026-03-01 Define 24h view of temperature screen layout
2026-03-15 add splash screen when sensor data is loading
2026-03-15 Button control
2026-03-15 Move SCD sensor to I2C bus 1
2026-03-24 Add first version of the case geometry
    [back lid.STEP, board.STEP, display frame.STEP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]
2026-03-29 Improve buttons
2026-03-29 Improve debouncing of the buttons
2026-03-29 Swap from SCD41 to BME280 to read temperature and humidity
    [main.py]
2026-03-31 Display system error also on screen
    [error_handling.py, main.py]
2026-10-05 Handle button actions on debounced release
    Sample buttons every 10 ms with a hard interrupt timer and debounce both
    press and release for 40 ms. Queue completed clicks during sensor reads
    and display updates; holding a button or releasing a startup-held button
    produces no action.
    Apply the mapping verified on the connected device: GP18 Home, GP19 Up,
    GP20 Down, and GP21 Refresh. Render navigation from cached sensor readings
    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
2026-10-05 Restore display state before full page refreshes
    Reinitialize the e-paper controller before full landscape updates and
    restore the RAM write window, entry direction, and address counters before
    each full, fast, or partial transfer. Share the landscape transfer logic
    while preserving pixel orientation.
    Retry pages after drawing runs out of memory without refreshing an
    incomplete frame. Route three consecutive failures through the existing
    error handler instead of waiting for another button action.
    Add regression coverage for repeated frames, partial/fast-to-full updates,
    and drawing retries. All 19 host-side tests pass; the uploaded firmware
    successfully displays its initial page after rest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
    [main.py, screen_waveshare_2p7inch_module.py]
2026-10-05 Document button mapping and display update behavior
    Describe the interactively verified Home, Up, Down, and Refresh mapping,
    release-triggered actions, debounce timing, queued clicks, and startup
    behavior. Document the MicroPython 1.27+ requirement and upload instructions.
    Explain display initialization and drawing retries, provide the host-side
    test command, and describe physical button checks on the Pico.
2026-10-05 Keep pressure min/max values and unit on one line
    Remove spaces around the min/max separator only for pressure history.
    Preserve the existing font, position, precision, and other history screens.
    The 1018.2/1018.2 hPa line measures 246 pixels with the actual font and fits
    within the 254 available pixels. Representative four-digit values were
    checked, and the updated screen manager was uploaded and startup verified.
2026-10-05 Hide the CO2 unit when the start-screen value would wrap
    Measure the formatted CO2 value and ppm unit using the active font.
    Omit the unit when the text exceeds the available width, and restore it
    on subsequent draws when the value fits again. Preserve number formatting,
    font size, position, and the air-quality label.
    Verified rendering for 400, 1000, 9999, 10000, and 65535, including rounding
    from 9999.6 to 10000 and returning to a smaller value. Uploaded the screen
    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
2026-10-05 Maintain e-paper reference images across refresh modes
    Allow landscape transfers to target either image RAM plane while retaining
    pixel orientation and resetting the write window and address counters.
    Seed both planes after full initialization, and synchronize the reference
    image only after partial or fast refreshes complete.
    Follow the reference driver's partial reset and border configuration and
    initialize the fast waveform before use. Document baseline handling and
    cover repeated frames, mode transitions, and failed partial refreshes.
    All 20 tests in this commit pass.
    [screen_waveshare_2p7inch_module.py]
2026-10-05 Clean the display after five soft updates
    Choose one refresh mode per cycle, prioritizing manual full refreshes,
    the five-soft-update limit, and the elapsed full-refresh interval.
    Use partial refreshes for newly measured frames and remove redundant
    automatic five-minute fast updates while preserving the fast-refresh API.
    Commit counters and timestamps only after successful transfers. Full
    refreshes reset the cleaning count and both timestamps, including refreshes
    requested by navigation or the Refresh button. Document the approximately
    three-minute cleaning cycle.
    Add scheduling tests for cleaning cycles, manual resets, full-refresh
    priority, transfer failures, completion timestamps, and c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
    [main.py]
2026-10-05 Reduce e-paper refresh latency with batched SPI transfers
    Send landscape frames in reusable 22-byte SPI batches and release chip select even if a transfer fails. Shorten reset and post-BUSY settling waits to 20 ms while retaining BUSY polling and both image RAM planes.
    Add coverage for pixel order, buffer reuse, transfer failures, and controller timing; document the changes. Pico benchmarks reduce full refreshes from 5.68 s to 2.09 s and partial refreshes from 4.23 s to 0.81 s.
    [screen_waveshare_2p7inch_module.py]
2026-10-05 Prioritize queued navigation over due sensor measurements
    Render pending button actions using cached readings before starting a due sensor measurement. Preserve the initial reading and measurement cadence, and resume sampling once pending clicks are handled.
    Add a main-loop regression test covering navigation priority and subsequent sampling, and document the behavior. All 31 tests pass.
2026-10-05 Redesign the start screen with a filled CO2 gauge and pressure
    Replace the three short-term charts with an eight-pixel CO2 gauge spanning 400-2500 ppm. Round the sector and fill ends, retain the existing quality thresholds, and keep the actual value and ppm label visible below the gauge.
    Keep temperature and humidity on the right with horizontal separators, and show approximate sea-level pressure with Low/Normal/High status beneath them. Configure site elevation through ALTITUDE_M, defaulting to 50 metres, and document how to adjust it. Pressure logs and history retain local sensor values.
    Fit text to its column using the bundled fonts. Add integration coverage for the elevation setting an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
    [main.py, screen_manager.py]
2026-10-05 Add a host preview and regression tests for the start screen
    Render the actual layout with the bundled bitmap fonts through a host framebuffer adapter. Provide a Pillow-based CLI with configurable CO2, pressure, altitude, and output path, and document its usage.
    Cover CO2 thresholds, fill growth and clamping, rounded end caps, altitude correction, pressure status boundaries, and text placement. Run these checks without device access or a Pillow dependency for the unit tests.
    Validation: all 41 tests pass; the final layout was uploaded, verified, and restarted successfully on the Pico.
2026-10-05 Add reusable climate icons and host preview support
    Extract the leaf, thermometer, and water-drop artwork from the existing start-screen background. Include monochrome PNG sources and one-byte-per-pixel device assets, with 32-pixel-high thermometer an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
    Extend the host preview adapter to load the same icon assets, validate their sizes and bounds, and record their positions for layout checks. Document the source artwork and existing attribution.
2026-10-05 Restore climate icons and remove the pressure heading
    Center a leaf beside CO2 and replace the temperature and humidity headings with larger icons before their values. Keep fallback fonts vertically centered beside the symbols.
    Retain the three divided climate rows, sea-level pressure in hPa, and Low/Normal/High status while removing the pressure heading. Update documentation and cover icon placement, asset dimensions, text overlap, and large-value font fallback while retaining pressure-correction tests.
    Validation: all 43 tests pass. The final code and icon assets were uploaded and verified on the Pico, which restarted successfully.
    [screen_manager.py]
2026-10-05 Thicken the hollow CO2 gauge outlines
    Increase the unfilled gauge contour from one pixel to two pixels while preserving the eight-pixel band, rounded ends, sector gaps, and fill behavior.
    Document the thicker outline and update pixel regression checks for the white interior, full fill, and rounded fill endpoint. All 44 tests pass; previews were inspected and the updated code was uploa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
2026-10-05 Fix history bars so active bins remain visible
    Draw oldest-first bins from their own timestamp toward the next newer bin, ending the active bin at Now. Correct zero and negative bar widths, clip drawing inside the chart frame, and keep subpixel bins visible without erasing them with separator lines.
    Extend the host framebuffer adapter and add regression coverage for the first sample, updates within the active bin, rollover, clipping, empty history, and timestamp wrapping. Document the 30-second refresh cadence, 30-minute averaging, and history reset on restart.
    Verified on the Pico with two real sensor readings 30 seconds apart and a successful partial refresh.
    [screen_manager.py]
2026-10-05 Stack history statistics with left-aligned values and units
    Show Current, Min, and Max in three rows on all four history pages. Left-align labels and complete value-and-unit pairs in separate columns, retaining one decimal place and n/a for empty extrema. Use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
    Add layout checks for all units, large values, empty history, and text overlap, plus a Pillow-based preview tool for populated and empty history pages. Document the final layout and preview usage.
    Validation: all 52 tests pass, previews were inspected, and the final code was uploaded and verified on the Pico, which restarted successfully.
2026-10-05 Add configurable CO2 trend arrows to the start screen
    Compare consecutive sensor readings and show a short, thick arrow beneath the CO2 assessment when the relative change exceeds the configured threshold. Default to 5%, hide arrows for startup or nonpositive readings, and retain the cached direction during button refreshes and navigation.
    Document threshold adjustment and add preview controls for rising, falling, and stable trends. Cover threshold boundaries, invalid readings, cached refresh behavior, and arrow placement with tests.
    Validation: all 55 unit tests pass; git diff --check is clean. Updated device files were backed up and uploaded with read-back verification.
    [main.py, screen_manager.py]
